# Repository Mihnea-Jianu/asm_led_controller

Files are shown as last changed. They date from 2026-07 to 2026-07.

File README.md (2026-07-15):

# ASM LED Controller

The ASM LED Controller Board is an algorithmic state machine, designed to store
and run a microprogram which controls the states of the 22 LEDs that make up the
on-board, heart-shaped LED array.

## Features

- 22 individually addressable LEDs.
- Microprograms up to 1023 microinstructions long.
- 3 separate clock speeds.
- Fully digital flash interface.

## Schematic Overview

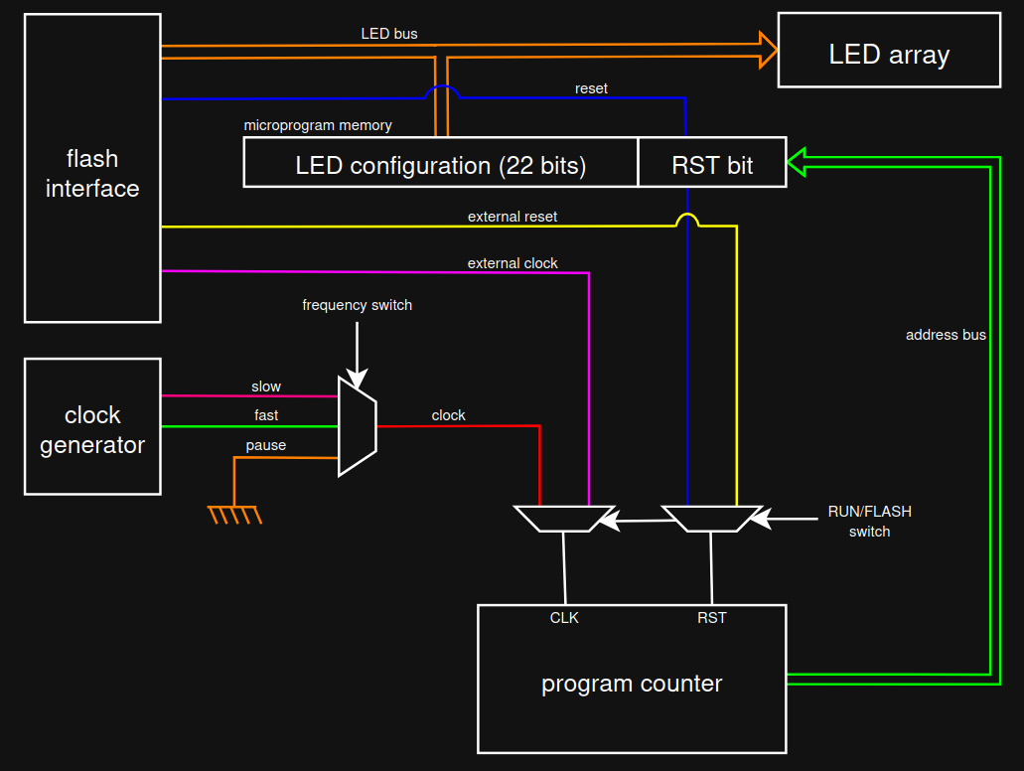
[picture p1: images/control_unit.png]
Microprogram Control Unit


### Clock Generator

The clock generator is simply a `CD4060BE binary counter`, which is setup to use
its built-in oscillator with the RC setup.

From the frequencies generated at the pins of the chip, I have selected a 
slow one `[Q8]` and a fast one `[Q7]`, and hooked them up to a SP3T slide
switch, for clock speed selection. The third pole of the slide switch is 
connected to GND, equivalent to a paused clock.

The output of this slide switch is the main clock of the circuit.

### Progam Counter

The program counter is another `CD4060BE binary counter`, whose outputs are used
to iterate through the addresses of the memory chips.

**When in RUN mode** 
- The counter is driven up by the pulse of the clock generator.
- The counter is reset when the current instruction's reset bit is pulled high.

**When in FLASH mode**
- The counter is driven up by the flash interface's XCLK.
- The counter is reset by the flash interface's XRST.

### Microprogram Memory

The microprogram memroy consists of 3 concatenated `AS6C1008-55PCN SRAM` chips.
Their addresses are 8 bits wide, so we have a total of 24 bits per address.

The current address of the memory chips is controlled by the program counter,
and the outputs of the memory chips go directly to the LED array.

**When in RUN mode**
- We read the LED configuration stored in memory, at the current address.
- We read the reset bit stored in memory, at the current address.

**When in FLASH mode**
- We write an LED configuration to the memory, at the current address.
- We write the reset bit to the memory, at the current address.

## Flashing

To flash the device, you will need a development board that has 26 usable digital
output pins, like the **Arduino Mega**.

The `asm_led_flasher.ino` sketch, under `software/`, is setup to use pins 22-47
of the Arduino Mega, which must be connected to the flash interface.

**The flash interface consists of 26 digital pins:**

<table>
    <thead> 
        <tr>
            <th>Pin</th> <th>Arduino Mega Pin</th> <th>Type</th> <th>Role</th>
        </tr> 
    </thead>
    <tbody>
        <tr>
            <td>L1 - L22</td>
            <td>26 - 47</td>
            <td>data pin</td>
            <td>load LED configurations into memory</td>
        </tr>
        <tr>
            <td>RST</td>
            <td>25</td>
            <td>data pin</td>
            <td>load reset bit into memory</td>
        </tr>
        <tr>
            <td>XWE</td>
            <td>24</td>
            <td>control pin</td>
            <td>write the values at the data pins into memory</td>
        </tr>
        <tr>
            <td>XRST</td>
            <td>23</td>
            <td>control pin</td>
            <td>reset the current address of the memory</td>
        </tr>
        <tr>
            <td>XCLK</td>
            <td>22</td>
            <td>control pin</td>
            <td>increment the current address of the memory</td>
        </tr>
    </tbody>
</table>

**Set the on-board switches to the following configuration:**

<table>
    <thead> 
        <tr>
            <th>Switch</th> <th>Position</th>
        </tr> 
    </thead>
    <tbody>
        <tr>
            <td>ON/OFF</td>
            <td>ON</td>
        </tr>
        <tr>
            <td>ON/OFF LED</td>
            <td>ON</td>
        </tr>
        <tr>
            <td>RUN/FLASH</td>
            <td>FLASH</td>
        </tr>
        <tr>
            <td>FREQUENCY</td>
            <td>PAUSE</td>
        </tr>
    </tbody>
</table>

Once everything is setup, connect the Arduino Mega to your computer, and upload
the `software/asm_led_flasher.ino` sketch to it.

- When the builtin LED lights up, you have 10 seconds to flip the top RUN/FLASH
switch back to RUN. 

- When the builtin LED lights up again, you can flip the bottom RUN/FLASH switch
back to RUN, disconnect the flash interface from the Arduino Mega, and unpause
the clock.

## Repository Contents

`hardware/`
- KiCad project files (schematic, layout).
- Custom libraries (symbols, footprints, 3D models, library tables).

`software/`
- Arduino IDE sketch, for flashing the board.

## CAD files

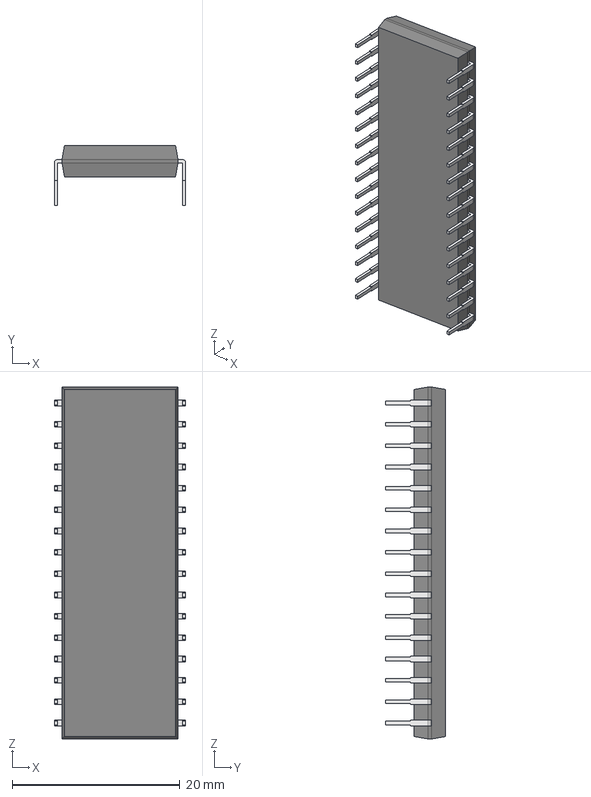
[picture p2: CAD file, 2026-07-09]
hardware/3dmodels/AS6C1008-55PCN/AS6C1008-55PCN.step
15.6 x 7.19 x 41.9 mm
Body001 (Mirror #1) x 17

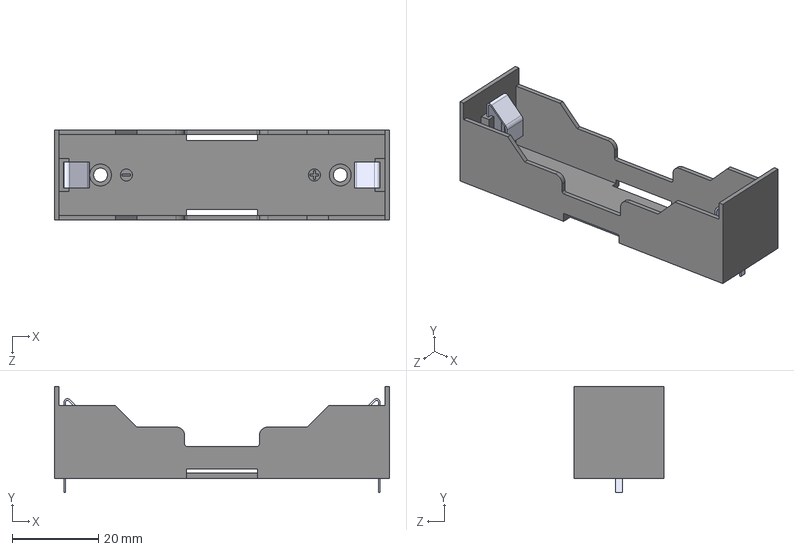
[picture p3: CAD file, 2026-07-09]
hardware/3dmodels/BH-18650-PC/BH-18650-PC.step
77.7 x 24.6 x 20.9 mm

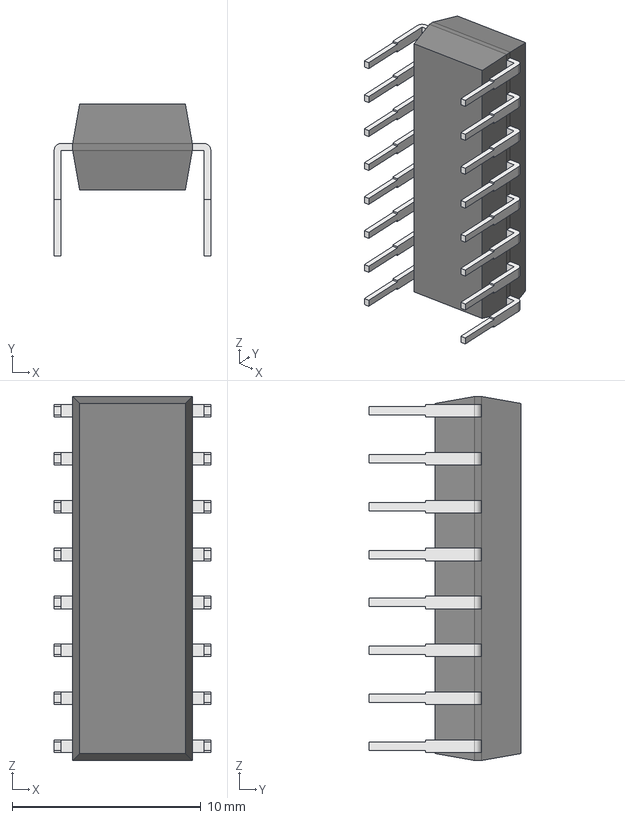
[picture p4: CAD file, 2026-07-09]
hardware/3dmodels/CD4060BE/CD4060BE.step
8.31 x 8.08 x 19.3 mm
Body001 (Mirror #1) x 9

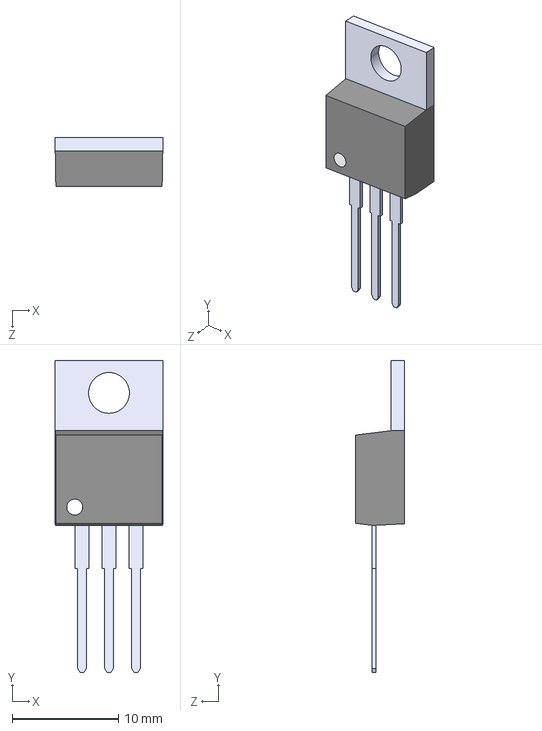
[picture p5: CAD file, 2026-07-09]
hardware/3dmodels/LM7805/LM7805.step
10.2 x 29.3 x 4.57 mm

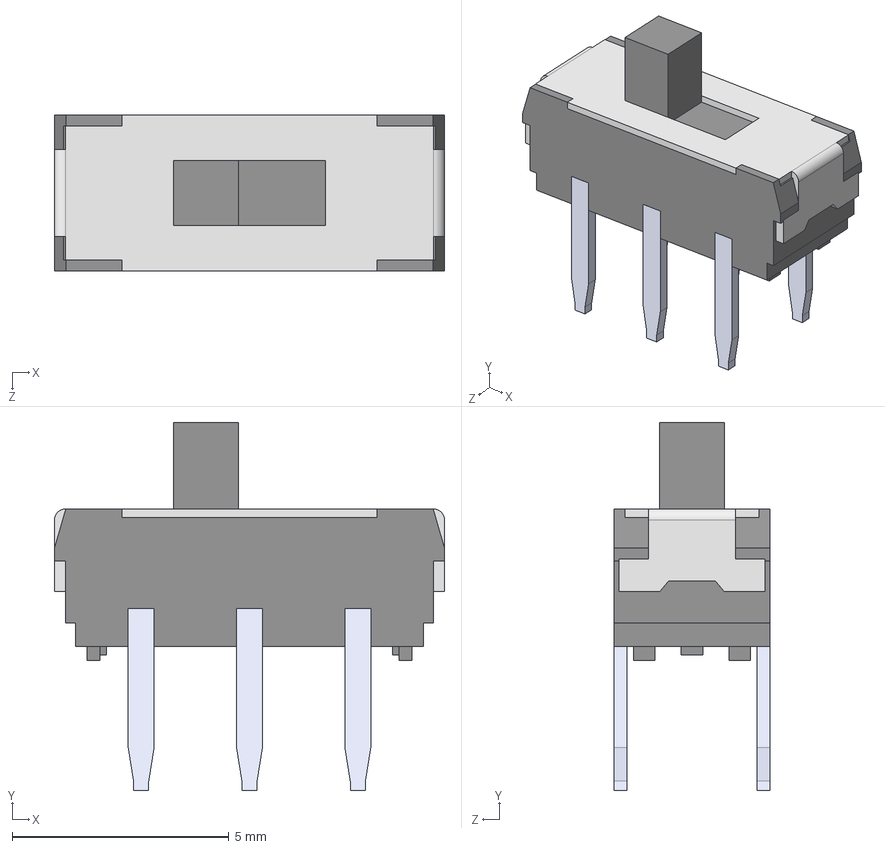
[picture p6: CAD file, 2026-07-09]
hardware/3dmodels/JS202011CQN/JS202011CQN.step
9.00 x 8.50 x 3.60 mm

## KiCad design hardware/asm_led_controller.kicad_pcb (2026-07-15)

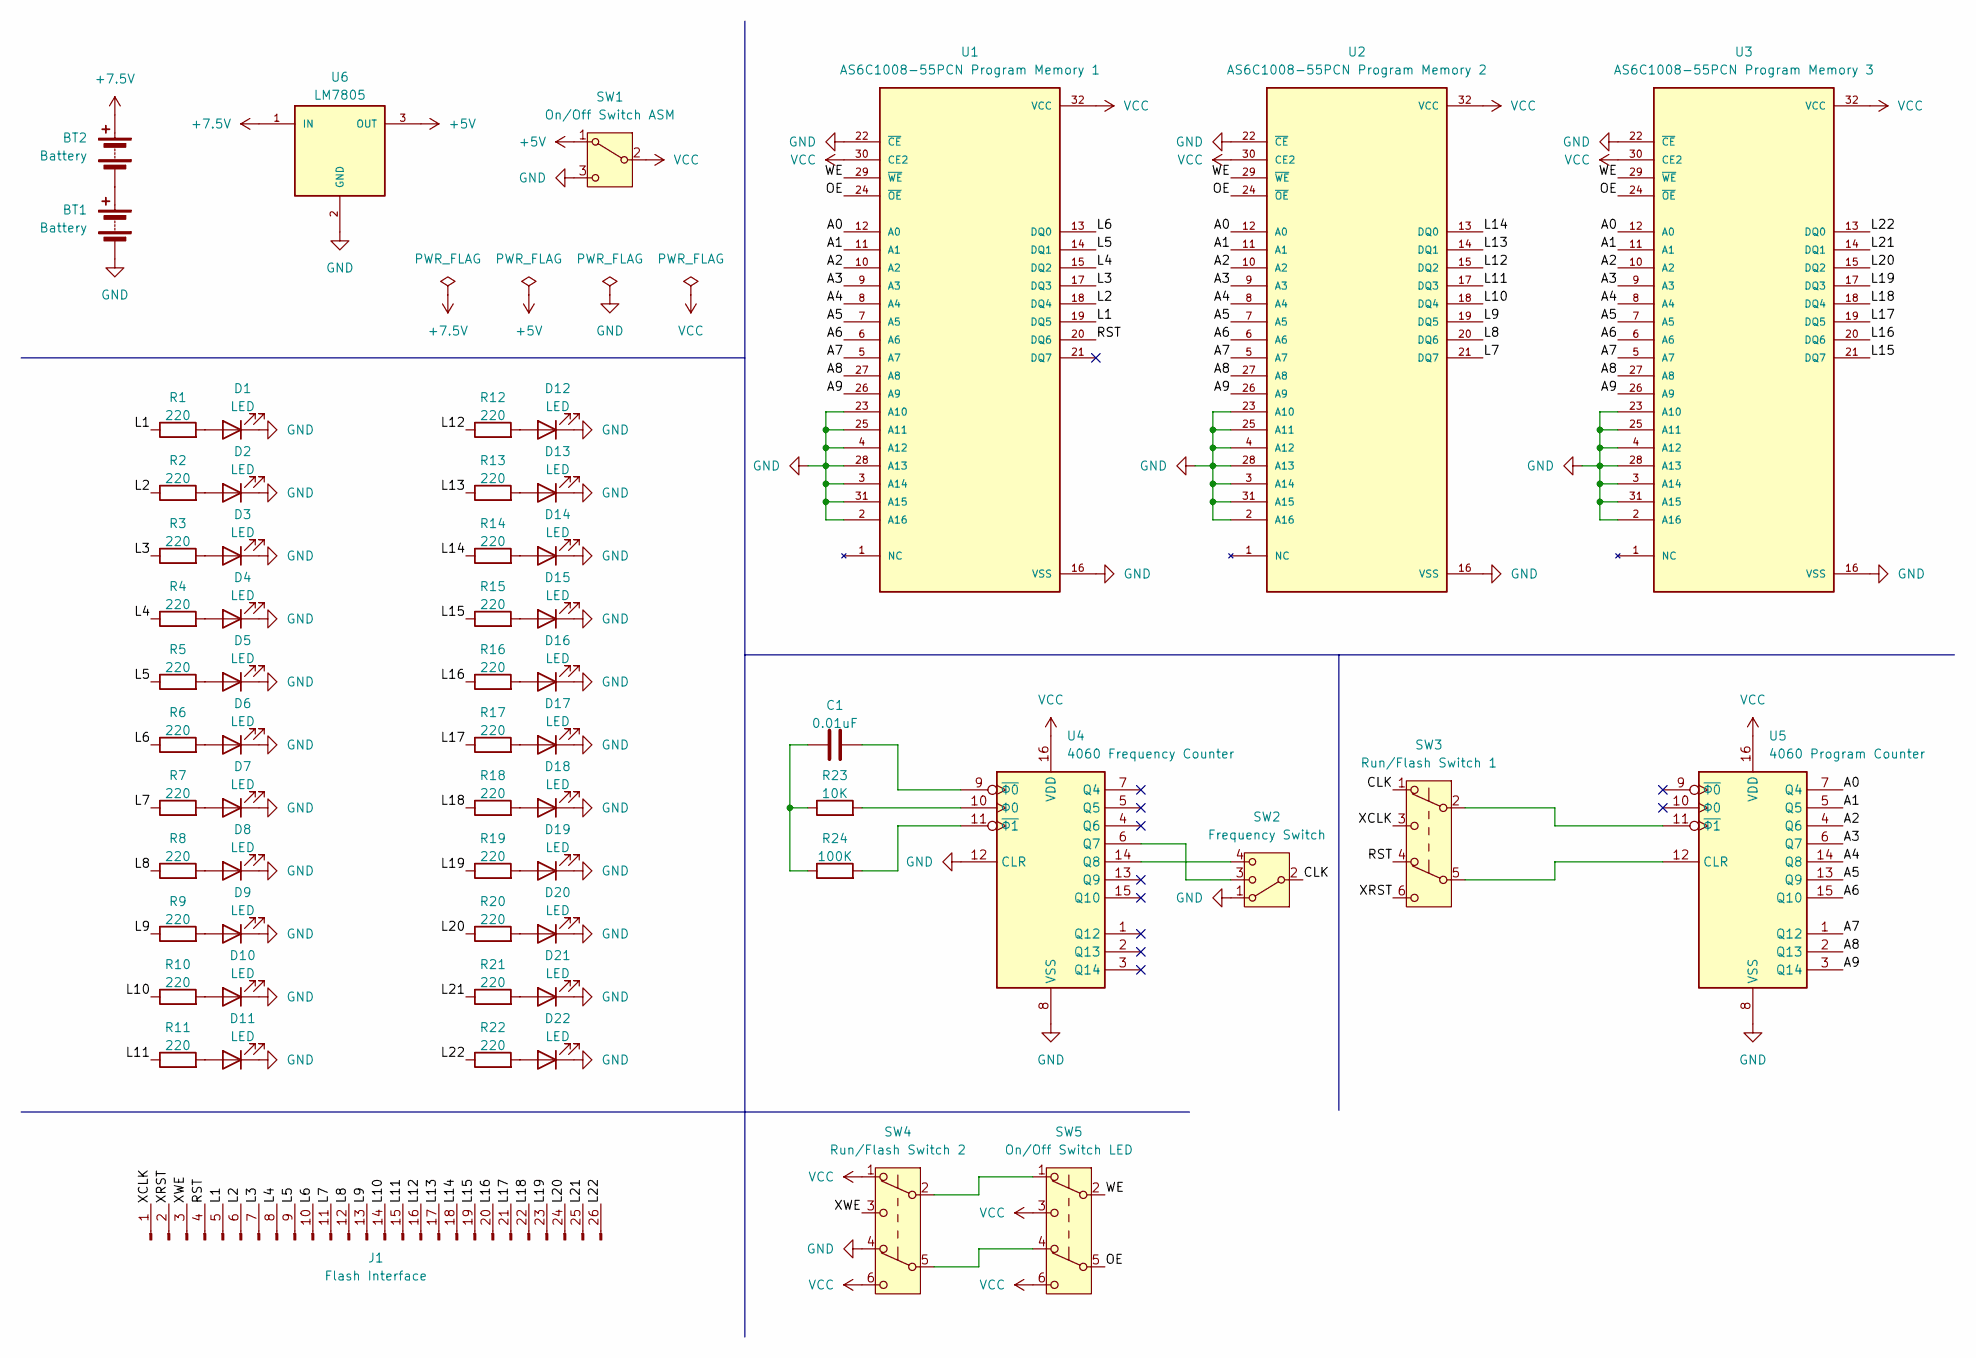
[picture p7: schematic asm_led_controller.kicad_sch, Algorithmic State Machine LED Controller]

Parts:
BT1, BT2: Battery; BAT_BH-18650-PC
C1: 0.01uF; C_Disc_D3.8mm_W2.6mm_P2.50mm
D1, D2, D3, D4, D5, D6, D7, D8, D9, D10, D11, D12, D13, D14, D15, D16, D17, D18, D19, D20, D21, D22: LED; LED_D5.0mm
J1: Flash Interface; PinHeader_2x13_P2.54mm_Vertical
R1, R2, R3, R4, R5, R6, R7, R8, R9, R10, R11, R12, R13, R14, R15, R16, R17, R18, R19, R20, R21, R22: 220; R_Axial_DIN0207_L6.3mm_D2.5mm_P7.62mm_Horizontal
R23: 10K; R_Axial_DIN0207_L6.3mm_D2.5mm_P7.62mm_Horizontal
R24: 100K; R_Axial_DIN0207_L6.3mm_D2.5mm_P7.62mm_Horizontal
SW1: On/Off Switch ASM; SW_Slide_SPDT_Straight_CK_OS102011MS2Q
SW2: Frequency Switch; OS102011MS8QP1
SW3: Run/Flash Switch 1; JS202011CQN
SW4: Run/Flash Switch 2; JS202011CQN
SW5: On/Off Switch LED; JS202011CQN
U1: AS6C1008-55PCN Program Memory 1; DIP1524W45P254L4191H419Q32
U2: AS6C1008-55PCN Program Memory 2; DIP1524W45P254L4191H419Q32
U3: AS6C1008-55PCN Program Memory 3; DIP1524W45P254L4191H419Q32
U4: 4060 Frequency Counter; DIP794W45P254L1969H508Q16
U5: 4060 Program Counter; DIP794W45P254L1969H508Q16
U6: LM7805; TO220

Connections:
+5V: SW1.1 (A), U6.3 (OUT); also elsewhere on the board
+7.5V: BT2.1 (+), U6.1 (IN)
/A0: U1.12 (A0), U2.12 (A0), U3.12 (A0), U5.7 (Q4)
/A1: U1.11 (A1), U2.11 (A1), U3.11 (A1), U5.5 (Q5)
/A2: U1.10 (A2), U2.10 (A2), U3.10 (A2), U5.4 (Q6)
/A3: U1.9 (A3), U2.9 (A3), U3.9 (A3), U5.6 (Q7)
/A4: U1.8 (A4), U2.8 (A4), U3.8 (A4), U5.14 (Q8)
/A5: U1.7 (A5), U2.7 (A5), U3.7 (A5), U5.13 (Q9)
/A6: U1.6 (A6), U2.6 (A6), U3.6 (A6), U5.15 (Q10)
/A7: U1.5 (A7), U2.5 (A7), U3.5 (A7), U5.1 (Q12)
/A8: U1.27 (A8), U2.27 (A8), U3.27 (A8), U5.2 (Q13)
/A9: U1.26 (A9), U2.26 (A9), U3.26 (A9), U5.3 (Q14)
/CLK: SW2.2, SW3.1 (A); also elsewhere on the board
/L1: J1.5, R1.1, U1.19 (DQ5); also elsewhere on the board
/L2: J1.6, R2.1, U1.18 (DQ4); also elsewhere on the board
/L3: J1.7, R3.1, U1.17 (DQ3); also elsewhere on the board
/L4: J1.8, R4.1, U1.15 (DQ2); also elsewhere on the board
/L5: J1.9, R5.1, U1.14 (DQ1); also elsewhere on the board
/L6: J1.10, R6.1, U1.13 (DQ0); also elsewhere on the board
/L7: J1.11, R7.1, U2.21 (DQ7); also elsewhere on the board
/L8: J1.12, R8.1, U2.20 (DQ6); also elsewhere on the board
/L9: J1.13, R9.1, U2.19 (DQ5); also elsewhere on the board
/L10: J1.14, R10.1, U2.18 (DQ4); also elsewhere on the board
/L11: J1.15, R11.1, U2.17 (DQ3); also elsewhere on the board
/L12: J1.16, R12.1, U2.15 (DQ2); also elsewhere on the board
/L13: J1.17, R13.1, U2.14 (DQ1); also elsewhere on the board
/L14: J1.18, R14.1, U2.13 (DQ0); also elsewhere on the board
/L15: J1.19, R15.1, U3.21 (DQ7); also elsewhere on the board
/L16: J1.20, R16.1, U3.20 (DQ6); also elsewhere on the board
/L17: J1.21, R17.1, U3.19 (DQ5); also elsewhere on the board
/L18: J1.22, R18.1, U3.18 (DQ4); also elsewhere on the board
/L19: J1.23, R19.1, U3.17 (DQ3); also elsewhere on the board
/L20: J1.24, R20.1, U3.15 (DQ2); also elsewhere on the board
/L21: J1.25, R21.1, U3.14 (DQ1); also elsewhere on the board
/L22: J1.26, R22.1, U3.13 (DQ0); also elsewhere on the board
/OE: SW5.5 (B), U1.24 (~OE), U2.24 (~OE), U3.24 (~OE); also elsewhere on the board
/RST: J1.4, SW3.4 (A), U1.20 (DQ6); also elsewhere on the board
/WE: SW5.2 (B), U1.29 (~WE), U2.29 (~WE), U3.29 (~WE); also elsewhere on the board
/XCLK: J1.1, SW3.3 (C); also elsewhere on the board
/XRST: J1.2, SW3.6 (C); also elsewhere on the board
GND: BT1.2 (-), D1.1 (K), D2.1 (K), D3.1 (K), D4.1 (K), D5.1 (K), D6.1 (K), D7.1 (K), D8.1 (K), D9.1 (K), D10.1 (K), D11.1 (K), D12.1 (K), D13.1 (K), D14.1 (K), D15.1 (K), D16.1 (K), D17.1 (K), D18.1 (K), D19.1 (K), D20.1 (K), D21.1 (K), D22.1 (K), SW1.3 (C), SW2.1, SW4.4 (A), U1.2 (A16), U1.3 (A14), U1.4 (A12), U1.16 (VSS), U1.22 (~CE), U1.23 (A10), U1.25 (A11), U1.28 (A13), U1.31 (A15), U2.2 (A16), U2.3 (A14), U2.4 (A12), U2.16 (VSS), U2.22 (~CE), U2.23 (A10), U2.25 (A11), U2.28 (A13), U2.31 (A15), U3.2 (A16), U3.3 (A14), U3.4 (A12), U3.16 (VSS), U3.22 (~CE), U3.23 (A10), U3.25 (A11), U3.28 (A13), U3.31 (A15), U4.8 (VSS), U4.12 (CLR), U5.8 (VSS), U6.2 (GND); also elsewhere on the board
unnamed: BT1.1 (+), BT2.2 (-)
unnamed: C1.2, R23.1, R24.1
unnamed: D1.2 (A), R1.2
unnamed: D2.2 (A), R2.2
unnamed: D3.2 (A), R3.2
unnamed: D4.2 (A), R4.2
unnamed: D5.2 (A), R5.2
unnamed: D6.2 (A), R6.2
unnamed: D7.2 (A), R7.2
unnamed: D8.2 (A), R8.2
unnamed: D9.2 (A), R9.2
unnamed: D10.2 (A), R10.2
unnamed: D11.2 (A), R11.2
unnamed: D12.2 (A), R12.2
unnamed: D13.2 (A), R13.2
unnamed: D14.2 (A), R14.2
unnamed: D15.2 (A), R15.2
unnamed: D16.2 (A), R16.2
unnamed: D17.2 (A), R17.2
unnamed: D18.2 (A), R18.2
unnamed: D19.2 (A), R19.2
unnamed: D20.2 (A), R20.2
unnamed: D21.2 (A), R21.2
unnamed: D22.2 (A), R22.2
unnamed: J1.3, SW4.3 (C)
unnamed: SW4.2 (B), SW5.1 (A)
unnamed: SW4.5 (B), SW5.4 (A)
unnamed 71: SW2.3, U4.6 (Q7); also elsewhere on the board
unnamed 72: SW2.4, U4.14 (Q8); also elsewhere on the board
unnamed: C1.1, U4.9 (~Φ0)
unnamed: R24.2, U4.11 (~Φ1)
unnamed: R23.2, U4.10 (Φ0)
unnamed: SW3.5 (B), U5.12 (CLR)
unnamed: SW3.2 (B), U5.11 (~Φ1)
VCC: SW1.2 (B), SW4.1 (A), SW4.6 (C), SW5.3 (C), SW5.6 (C), U1.30 (CE2), U1.32 (VCC), U2.30 (CE2), U2.32 (VCC), U3.30 (CE2), U3.32 (VCC), U4.16 (VDD), U5.16 (VDD); also elsewhere on the board

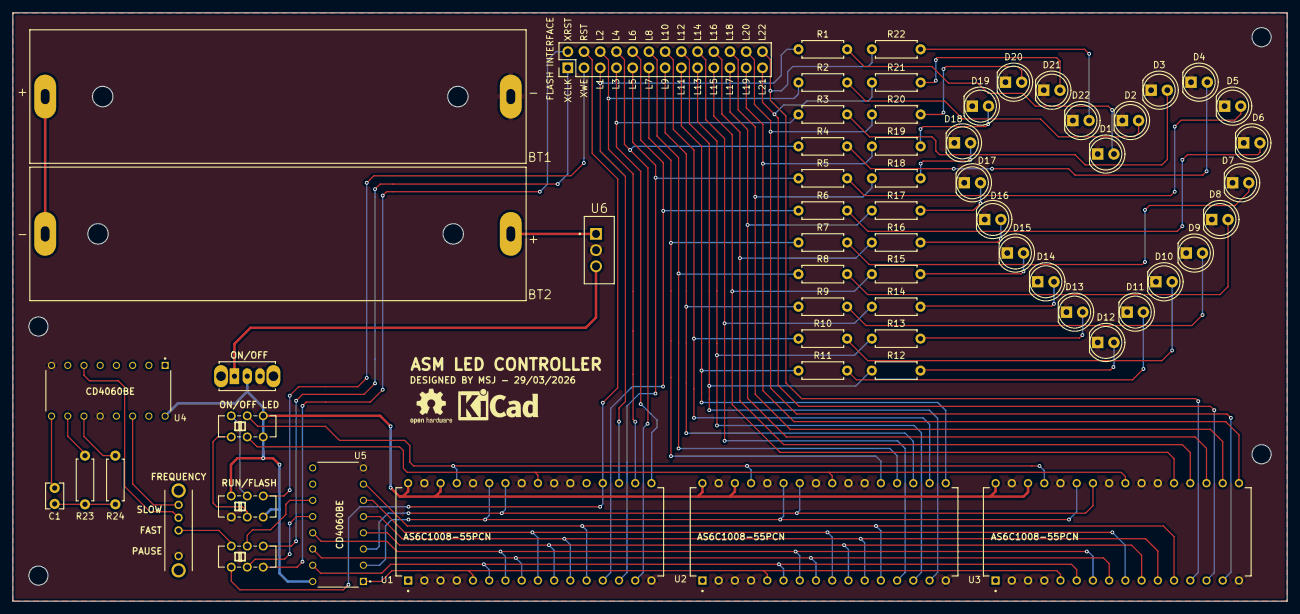
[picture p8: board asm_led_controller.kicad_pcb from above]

Board: 2 copper layers, 199.5 x 92.1 mm, 61 parts (0 on the bottom side), 76 nets.

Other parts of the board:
FLASH INTERFACE: Flash Interface; PinHeader_2x13_P2.54mm_Vertical
FREQUENCY: Frequency Switch; OS102011MS8QP1
ON/OFF: On/Off Switch ASM; SW_Slide_SPDT_Straight_CK_OS102011MS2Q
ON/OFF LED: On/Off Switch LED; JS202011CQN
RUN/FLASH: Run/Flash Switch 2; JS202011CQN

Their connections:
+5V: ON/OFF.1 (A); also elsewhere on the board
/CLK: FREQUENCY.2; also elsewhere on the board
/L1: FLASH INTERFACE.5; also elsewhere on the board
/L2: FLASH INTERFACE.6; also elsewhere on the board
/L3: FLASH INTERFACE.7; also elsewhere on the board
/L4: FLASH INTERFACE.8; also elsewhere on the board
/L5: FLASH INTERFACE.9; also elsewhere on the board
/L6: FLASH INTERFACE.10; also elsewhere on the board
/L7: FLASH INTERFACE.11; also elsewhere on the board
/L8: FLASH INTERFACE.12; also elsewhere on the board
/L9: FLASH INTERFACE.13; also elsewhere on the board
/L10: FLASH INTERFACE.14; also elsewhere on the board
/L11: FLASH INTERFACE.15; also elsewhere on the board
/L12: FLASH INTERFACE.16; also elsewhere on the board
/L13: FLASH INTERFACE.17; also elsewhere on the board
/L14: FLASH INTERFACE.18; also elsewhere on the board
/L15: FLASH INTERFACE.19; also elsewhere on the board
/L16: FLASH INTERFACE.20; also elsewhere on the board
/L17: FLASH INTERFACE.21; also elsewhere on the board
/L18: FLASH INTERFACE.22; also elsewhere on the board
/L19: FLASH INTERFACE.23; also elsewhere on the board
/L20: FLASH INTERFACE.24; also elsewhere on the board
/L21: FLASH INTERFACE.25; also elsewhere on the board
/L22: FLASH INTERFACE.26; also elsewhere on the board
/OE: ON/OFF LED.5 (B); also elsewhere on the board
/RST: FLASH INTERFACE.4; also elsewhere on the board
/WE: ON/OFF LED.2 (B); also elsewhere on the board
/XCLK: FLASH INTERFACE.1; also elsewhere on the board
/XRST: FLASH INTERFACE.2; also elsewhere on the board
/XWE: FLASH INTERFACE.3, RUN/FLASH.3 (C)
GND: FREQUENCY.1, ON/OFF.3 (C), RUN/FLASH.4 (A); also elsewhere on the board
unnamed: ON/OFF LED.1 (A), RUN/FLASH.2 (B)
unnamed: ON/OFF LED.4 (A), RUN/FLASH.5 (B)
unnamed 71: FREQUENCY.3; also elsewhere on the board
unnamed 72: FREQUENCY.4; also elsewhere on the board
VCC: ON/OFF.2 (B), ON/OFF LED.3 (C), ON/OFF LED.6 (C), RUN/FLASH.1 (A), RUN/FLASH.6 (C); also elsewhere on the board

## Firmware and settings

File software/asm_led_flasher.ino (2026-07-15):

// Each row is an instruction containing an LED configuration and the reset bit.
const unsigned char source[] = {
//  L1  L2  L3  L4  L5  L6  L7  L8  L9  L10 L11 L12 L13 L14 L15 L16 L17 L18 L19 L20 L21 L22 RST 
    1,  1,  1,  1,  0,  0,  0,  0,  0,  0,  0,  0,  0,  0,  0,  0,  0,  0,  0,  1,  1,  1,  0,
    1,  1,  1,  1,  1,  0,  0,  0,  0,  0,  0,  0,  0,  0,  0,  0,  0,  0,  0,  0,  1,  1,  0,
    1,  1,  1,  1,  1,  1,  0,  0,  0,  0,  0,  0,  0,  0,  0,  0,  0,  0,  0,  0,  0,  1,  0,
    1,  1,  1,  1,  1,  1,  1,  0,  0,  0,  0,  0,  0,  0,  0,  0,  0,  0,  0,  0,  0,  0,  0,
    0,  1,  1,  1,  1,  1,  1,  1,  0,  0,  0,  0,  0,  0,  0,  0,  0,  0,  0,  0,  0,  0,  0,
    0,  0,  1,  1,  1,  1,  1,  1,  1,  0,  0,  0,  0,  0,  0,  0,  0,  0,  0,  0,  0,  0,  0,
    0,  0,  0,  1,  1,  1,  1,  1,  1,  1,  0,  0,  0,  0,  0,  0,  0,  0,  0,  0,  0,  0,  0,
    0,  0,  0,  0,  1,  1,  1,  1,  1,  1,  1,  0,  0,  0,  0,  0,  0,  0,  0,  0,  0,  0,  0,
    0,  0,  0,  0,  0,  1,  1,  1,  1,  1,  1,  1,  0,  0,  0,  0,  0,  0,  0,  0,  0,  0,  0,
    0,  0,  0,  0,  0,  0,  1,  1,  1,  1,  1,  1,  1,  0,  0,  0,  0,  0,  0,  0,  0,  0,  0,
    0,  0,  0,  0,  0,  0,  0,  1,  1,  1,  1,  1,  1,  1,  0,  0,  0,  0,  0,  0,  0,  0,  0,
    0,  0,  0,  0,  0,  0,  0,  0,  1,  1,  1,  1,  1,  1,  1,  0,  0,  0,  0,  0,  0,  0,  0,
    0,  0,  0,  0,  0,  0,  0,  0,  0,  1,  1,  1,  1,  1,  1,  1,  0,  0,  0,  0,  0,  0,  0,
    0,  0,  0,  0,  0,  0,  0,  0,  0,  0,  1,  1,  1,  1,  1,  1,  1,  0,  0,  0,  0,  0,  0,
    0,  0,  0,  0,  0,  0,  0,  0,  0,  0,  0,  1,  1,  1,  1,  1,  1,  1,  0,  0,  0,  0,  0,
    0,  0,  0,  0,  0,  0,  0,  0,  0,  0,  0,  0,  1,  1,  1,  1,  1,  1,  1,  0,  0,  0,  0,
    0,  0,  0,  0,  0,  0,  0,  0,  0,  0,  0,  0,  0,  1,  1,  1,  1,  1,  1,  1,  0,  0,  0,
    0,  0,  0,  0,  0,  0,  0,  0,  0,  0,  0,  0,  0,  0,  1,  1,  1,  1,  1,  1,  1,  0,  0,
    0,  0,  0,  0,  0,  0,  0,  0,  0,  0,  0,  0,  0,  0,  0,  1,  1,  1,  1,  1,  1,  1,  0,
    1,  0,  0,  0,  0,  0,  0,  0,  0,  0,  0,  0,  0,  0,  0,  0,  1,  1,  1,  1,  1,  1,  0,
    1,  1,  0,  0,  0,  0,  0,  0,  0,  0,  0,  0,  0,  0,  0,  0,  0,  1,  1,  1,  1,  1,  0,
    1,  1,  1,  0,  0,  0,  0,  0,  0,  0,  0,  0,  0,  0,  0,  0,  0,  0,  1,  1,  1,  1,  0,
    1,  1,  1,  1,  1,  1,  1,  1,  1,  1,  1,  1,  1,  1,  1,  1,  1,  1,  1,  1,  1,  1,  1  // Reset instruction, do not remove.
};

const unsigned char instructionSize = 23;

// Pin mapping.
const unsigned char led[22] = {26, 27, 28, 29, 30, 31, 32, 33, 34, 35, 36, 37, 38, 39, 40, 41, 42, 43, 44, 45, 46, 47};
const unsigned char xclk = 22;
const unsigned char xrst = 23;
const unsigned char xwe  = 24;
const unsigned char rst  = 25;

void flash() {
  // Reset the program counter.
  digitalWrite(xrst, HIGH);
  delay(100);
  digitalWrite(xrst, LOW);
  delay(100);

  // Iterate through instructions and write them.
  for(int i = 0; i < sizeof(source); i += instructionSize) {
    // Load the LED configuration from the current instruction.
    for(int j = 0; j < sizeof(led); j++) {
      digitalWrite(led[j], source[i + j]);
    }

    // Load the reset bit from the current instruction.
    digitalWrite(rst, source[i + instructionSize - 1]);

    // Let the data stabilise.
    delay(100);

    // Write the data.
    digitalWrite(xwe, LOW);
    delay(100);
    digitalWrite(xwe, HIGH);
    delay(100);

    // Advance to the next memory address.
    for(int j = 0; j < 8; j++) { // Must be done 8 times becuase the program counter advances on the 8th pulse of the clock.
      digitalWrite(xclk, HIGH);
      delay(100);
      digitalWrite(xclk, LOW);
      delay(100);
    }
  }

  // Turn on the builtin LED to signal that user has 10 seconds to flip the top RUN/FLASH switch back to RUN.
  digitalWrite(LED_BUILTIN, HIGH);
  delay(10000);
  digitalWrite(LED_BUILTIN, LOW);

  // Reset program counter.
  digitalWrite(xrst, HIGH);
  delay(100);
  digitalWrite(xrst, LOW);
  delay(100);

  // Turn on built-in LED to signal that the user can flip the bottom RUN/FLASH switch back to RUN,
  // as well as disconnect the flash interface and unpause the clock.
  digitalWrite(LED_BUILTIN, HIGH);
}

void setup() {
  // Set all pins to output mode and give them an initial state.
  for(int i = 0; i < sizeof(led); i++) {
    pinMode(led[i], OUTPUT);
    digitalWrite(led[i], LOW);
  }

  pinMode(LED_BUILTIN, OUTPUT);
  pinMode(rst,         OUTPUT);
  pinMode(xrst,        OUTPUT);
  pinMode(xclk,        OUTPUT);
  pinMode(xwe,         OUTPUT);

  digitalWrite(LED_BUILTIN, LOW);
  digitalWrite(rst,         LOW);
  digitalWrite(xrst,        LOW);
  digitalWrite(xclk,        LOW);
  digitalWrite(xwe,         HIGH);

  // Let the outputs stabilise and run the flash function.
  delay(100);
  flash();
}

void loop() {

}

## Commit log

2026-07-06 added schematic and layout files
    [asm_led_controller.kicad_pcb, asm_led_controller.kicad_sch]
2026-07-09 Restructured the project tree
    [AS6C1008-55PCN.step, BH-18650-PC.step, CD4060BE.step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]
2026-07-09 Removed old project structure
    [asm_led_controller.kicad_pcb, asm_led_controller.kicad_sch]
2026-07-09 Readded silkscreen labels
    [asm_led_controller.kicad_pcb]
2026-07-15 Updated frequency switch silkscreen
    [asm_led_controller.kicad_pcb]
